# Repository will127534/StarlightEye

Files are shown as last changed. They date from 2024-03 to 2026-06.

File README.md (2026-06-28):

# StarlightEye: OpenSource IMX585 Camera Board for Raspberry Pi
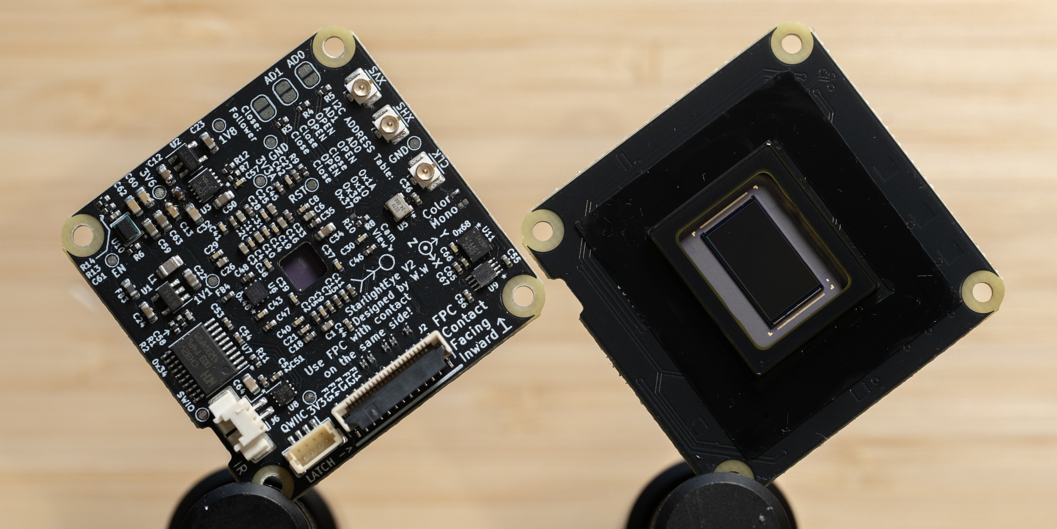
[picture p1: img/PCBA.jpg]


## Version 2.0 Changes
Mainly changed the power tree so now it does not require an external 5V input but the board can take all the power from FPC directly, there is a step-up converter that will step it up to 3.6V which is powering both IR filter switch (When used) and 3.3V analog LDO/1.8V Digital LDO input. By doing so the board size can finally shrink down to a perfect 39mm square which also matches the latest OneInchEye.  

The only down side is that the Step-Up convter I'm using here (TPSM83100) is expensive AF, I was going to pick TPSM81033 that is both cheaper and better but I have been waiting it to go on the market for four month now, I don't know when TI will actually get them ship to Mouser so for now I'm stuck with TPSM83100.  

_DSC9428

## Introduction
Welcome to the **StarlightEye** project, an open-source camera board designed for Raspberry Pi Compute Module 4 boards using the IMX585. This project aims to provide a high-quality, affordable, and accessible camera module for advanced Raspberry Pi projects. The board is designed using KiCad v6, a popular open-source electronics design automation (EDA) software.

StarlightEye captures stunning high-resolution images and videos with improved low-light performance and dynamic range. It's perfect for photography enthusiasts, developers, and makers who want to level up their Raspberry Pi projects with a powerful camera.  
  
Also see [Quick Start Guide](https://github.com/will127534/StarlightEye/wiki/StarlightEye-Quick-Start-Guide)

## Features
* IMX585 sensor
* **Open-source hardware and software**
* Integrated IR filter switch control via I2C based on CH32V003
* Integrated TMP117 temperature sensor
* Compatible with Raspberry Pi5 and Raspberry Pi Compute Module 4 boards with a 22-pin FPC connector and 4-lane MIPI-CSI (same pinout as Raspberry Pi Compute Module 4 IO Board)
* Limited amount on [https://shop.willwhang.dev/](https://shop.willwhang.dev/) for sell

## Notes
* Gerber and CPL file for JLCPCB is under /Gerber
* [Interactive BOM](https://htmlpreview.github.io/?https://github.com/will127534/StarlightEye/blob/main/bom/ibom.html) [(provided by InteractiveHtmlBom)
](https://github.com/openscopeproject/InteractiveHtmlBom) and JLCPCB BOM under /bom
* Source Code for CH32V003 based I2C controlled IR Filter Switch and Python code on RPI under /software

## Support
For questions, issues, or suggestions, please open an issue in the [GitHub repository](https://github.com/will127534/StarlightEye/issues)

## Schematic
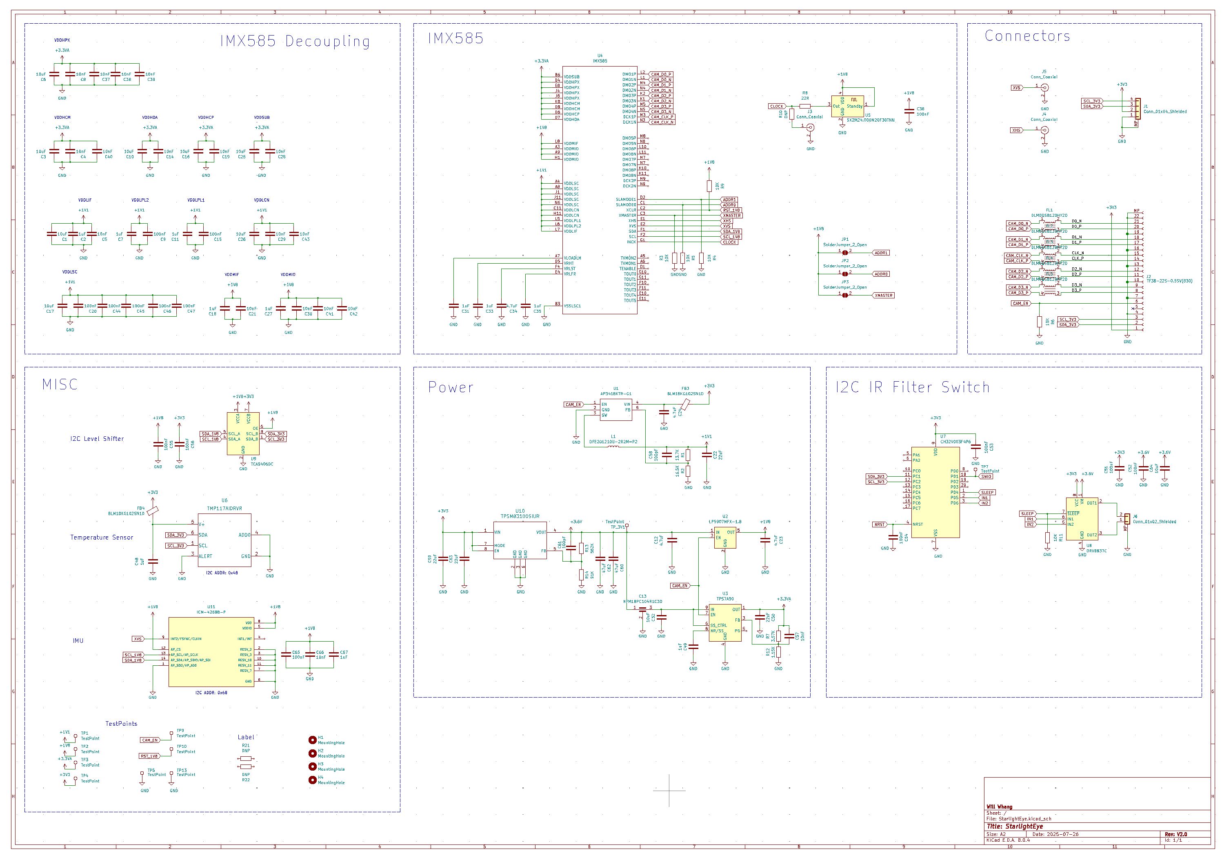
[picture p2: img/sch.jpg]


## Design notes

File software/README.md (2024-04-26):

# I2C IR Filter Switch

## Introduction
The I2C IR filter switch is based on CH32V003 acted as a I2C device, by default the I2C address is 0x34 and by writing 0x01 to enable IR filter or writing 0x00 to disable IR filter. The I2C connection is shared with the CMOS sensor on the StarlightEye.

## Install Python script on RPI
To install the script to your RPI, run the following cmd  
```
sudo wget https://raw.githubusercontent.com/will127534/StarlightEye/master/software/IRFilter -O /usr/local/bin/IRFilter && sudo chmod +x /usr/local/bin/IRFilter
```

## Example
The I2C bus will depend on which port you connect the StarlightEye to RPI5, by default CAM1 maps to I2C port 4 and CAM1 to port 6.
The default of the script is on CAM1, but you can add '--i2c-bus' flag to change it to other ports.
To enable IR filter:
```
IRFilter --enable
```
To disable IR filter:
```
IRFilter --disable
```

## Support
For questions, issues, or suggestions, please open an issue in the [GitHub repository](https://github.com/will127534/StarlightEye/issues)

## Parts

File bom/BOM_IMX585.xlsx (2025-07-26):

Comment | Designator | Footprint | JLCPCB Part #（optional）
NFM18PC104R1C3D | C13 | NFM18CC101R1C3D | C111493
10uF | C25,C26,C6,C10,C1,C16,C17,C3 | C_0402_1005Metric | C15525
1uF | C33,C27,C31,C18,C7,C67,C48,C49,C35,C2,C11 | C_0402_1005Metric | C52923
4.7uF | C34,C24,C23,C12 | C_0603_1608Metric | C19666
10nF | C43,C4,C21,C29,C28,C5,C8,C37,C57,C41,C66,C39,C42,C14,C19,C40,C38,C30 | C_0402_1005Metric | C15195
100nF | C52,C36,C54,C47,C55,C9,C20,C56,C51,C15,C53,C46,C44,C45,C65 | C_0402_1005Metric | C1525
22uF | C59,C50,C22,C63 | C_0603_1608Metric | C59461
47uF | C60,C62 | C_0603_1608Metric | C140782
100pF | C61,C58 | C_0402_1005Metric | C1546
10uF | C64,C32 | C_0603_1608Metric | C96446
BLM18KG102SN1D | FB3 | L_0603_1608Metric | C160982
BLM15PX330SZ1D | FB4 | L_0402_1005Metric | C2661673
DLM0QSB120HY2D | FL4,FL3,FL5,FL1,FL2 | DLM0QSB120HY2D | C3211477
Conn_01x04_Shielded | J1 | JST_SH_BM04B-SRSS-TB_1x04-1MP_P1.00mm_Vertical | C160390
TF38-22S-0.5SV(830) | J2 | TF38-22S-0.5SV(830) | C6552695
Conn_Coaxial | J4,J5,J3 | U.FL_Hirose_U.FL-R-SMT-1_Vertical | C5137195
Conn_01x02_Shielded | J6 | Molex_PicoBlade_53261-0271_1x02-1MP_P1.25mm_Horizontal | C189700
DFE201210U-2R2M=P2 | L1 | L_0805_2012Metric | C2049745
13.7K | R1 | R_0402_1005Metric | C25854
1.15K | R12 | R_0402_1005Metric | C29401
562K | R13 | R_0402_1005Metric | C48838
91K | R14 | R_0402_1005Metric | C4147
16.5K | R2 | R_0402_1005Metric | C25857
10K | R3,R11,R6,R5,R9,R4 | R_0402_1005Metric | C25744
3.57K | R7 | R_0402_1005Metric | C137991
22R | R8 | R_0402_1005Metric | C25092
AP3418KTR-G1 | U1 | SOT-23-5 | C500769
TPSM83100SIUR | U10 | MICROSIP8_SIU_TEX-L | C20346010
ICM-42688-P | U11 | PQFN50P300X250X97-14N | C1850418
LP5907MFX-1.8 | U2 | SOT-23-5 | C92498
TPS7A90 | U3 | Texas_S-PDSO-N10_EP1.2x2mm | C840111
SX2M24.000M20F30TNN | U5 | Oscillator_SMD_Abracon_ASDMB-4Pin_2.5x2.0mm | C2901600
TMP117AIDRVR | U6 | TMP117AIDRVR | C699536
CH32V003F4P6 | U7 | TSSOP-20_4.4x6.5mm_P0.65mm | C5187096
DRV8837C | U8 | WSON-8-1EP_2x2mm_P0.5mm_EP0.9x1.6mm | C191000
TCA9406DC | U9 | TCA9406DCUR | C840107
IMX585 | U4 | IMX283

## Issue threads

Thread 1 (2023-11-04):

LCSC part numbers?

tlalexander, 2023-11-04:
Hello,
Do you by chance have LCSC part numbers for this board? Some of them are easy to figure out, but I started trying to find an equivalent part for the Hirose FFC connector and I realized I should just ask first.
Thanks!

will127534, 2023-11-04:
check https://github.com/will127534/OneInchEye/blob/main/bom/BOM_JLCSMT.csv#L11
They are mostly the same.

I haven't send it to JLCPCB yet so don't have any part numbers to share yet.

will127534, 2023-11-04:
Actually I probably want to open this until I have the design send to JLCPCB

tlalexander, 2023-11-04:
Okay thanks!

tlalexander, 2023-11-04:
Ah interesting that the Hirose connector is marked as discontinued on LCSC with no stock indicated.
https://www.lcsc.com/product-detail/FFC-FPC-Connectors_HRS-Hirose-FH12A-22S-0-5SH-55_C3168813.html
https://jlcpcb.com/partdetail/Hirose-FH12A_22S_0_5SH_55/C3168813

will127534, 2023-11-04:
I guess you can swap it to a bottom-contact type:
[https://www.lcsc.com/product-detail/FFC-FPC-Connectors_HRS-Hirose-FH12-22S-0-5SH-55_C597981.html](https://www.lcsc.com/product-detail/FFC-FPC-Connectors_HRS-Hirose-FH12-22S-0-5SH-55_C597981.html)

But then you will need a FPC cable with one contact on the top and the other on the bottom of the FPC

will127534, 2023-11-04:
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

Some thing like this

tlalexander, 2023-11-04:
Okay great, thank you for finding a suitable part! I have seen cables like that around, shouldn't be too much trouble thanks.

phodina, 2024-01-12:
Hi @will127534 ,
speaking of the BOM and the parts - how do you solder the image sensor?

Do you let PCBWAY, JLCPCB or other manufacturer take care of that or do you solder the IMX585 IC yourself?

will127534, 2024-01-18:
@phodina I use low temperature paste and heat the board from the bottom with either heatgun or IR PCB pre-heater.

will127534, 2024-03-24:
Closing the issue with the updated design files

Closed 2024-03-24.

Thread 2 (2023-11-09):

IMX585 driver

petergerten, 2023-11-09:
That's a very interesting project!
I can't find the IMX585 driver - any hints?

will127534, 2023-11-10:
I do have the driver but I'm in the progress of updating it for RPI5, here is the V4l2subdevice driver sketch:
[https://gist.github.com/will127534/f734a32b18b44d57448b4e46d07bb1c7](https://gist.github.com/will127534/f734a32b18b44d57448b4e46d07bb1c7)

Will release once I sort out the issue.

petergerten, 2023-11-13:
@will127534 thanks!

In general can you tell me how much board specific this driver is?
E.g. to port it to a non-pi board with MIPI/CSI interface

will127534, 2023-11-13:
This is very specific for RPI, which non-pi board are you looking into?
If you know how to write camera driver for other platform I think it is actually not that bad because the driver only implements one mode and it is setup with the init-register array, so you just need to send those and setup the CSI receiver accordingly.

petergerten, 2023-11-20:
sorry for the late reply, I missed this message.

I am looking for integration with Qualcomm RB5 (https://www.qualcomm.com/developer/robotics-rb5-development-kit)

will127534, 2024-01-21:
[https://github.com/will127534/imx585-v4l2-driver/tree/main](https://github.com/will127534/imx585-v4l2-driver/tree/main)

Closed 2024-01-21.

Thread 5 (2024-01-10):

imx585 datasheet or description

deecct, 2024-01-10:
Hello! You made great work and it helps a lot for creating driver for image sensor.
I try to connect imx678 sensor to rockchip rv1126. I am starting to work on linux kernel driver for this images sensor. The imx678 sensor is very similar to imx585, at least the have identical resolution and both based on startvis2. Could you privately share the datasheet for imx585? Or may be sections that related with registers, functional and operation descriptions?

phodina, 2024-01-12:
@deecct This might help
 https://gitlab.com/kicad/libraries/kicad-symbols/-/merge_requests/4186#note_1723899202

node3112, 2024-01-18:
@deecct If you need the application notes and software reference manual, I am happy to share privately.

node3112, 2024-01-18:
Actually never mind, I'll just share here publicly.
[IMX585-AAQJ1.zip](https://github.com/will127534/StarlightEye/files/13975511/IMX585-AAQJ1.zip)

robertimorrison, 2024-02-21:
I have the full imx585 datasheet if you would like it.  Why sony tries to keep this stuff top secret is beyond me.

KharlamovVadim, 2024-02-27:
> I have the full imx585 datasheet if you would like it. Why sony tries to keep this stuff top secret is beyond me.

Hello!

Currently I am working on a project based on Novatek NT9856x EVB and IMX678. I have a datasheet from Sony, but it does not contain register addressing and contains a link to external application notes. Therefore, I am unable to adapt the IMX678 sensor to Novatek SDK based on Linux. I was able to find a mention of the sensor I was interested in only in this thread.

Could you please share the mentioned information about IMX678 (IMX585) in a private message? Perhaps there are also examples of driver implementations for this type of sensor?

If suddenly you have similar information on IMX471 and IMX363, then this is absolutely magic! These two types of sensors are next in line for driver development for this evaluation board.

If the other authors of the thread can also help, I would be very grateful!

KharlamovVadim, 2024-02-27:
> @deecct If you need the application notes and software reference manual, I am happy to share privately.

Hello!

Can you share privately to me please?

robertimorrison, 2024-02-27:
Vadim -- the datasheet I have is mostly about the hardware.  It describes how to write to chip registers, there is only a reference to an excel file (IMX585_Standard_Register_Setting) that probably gives better description of where they are and what they do.  I dont have the spreadsheet, likely essential for writing a driver.

I dont know how exactly to get private contact with you you can text me at 561-762-3314 (USA).

deecct, 2024-02-27:
@KharlamovVadim. I don't have full register map for imx678, but I have found purposes and values of several most important registers related with operation modes of this sensor. I can share it with you. The implementation of driver is similar to another sony's sensors if you use it as v4l2 subdevice.

P.S. I found an example of implementation here in github with "imx678" keyword. Maybe this [imx678.c](https://github.com/hailo-ai/linux-yocto-hailo/blob/b72dd07c41f7d7c74d979eb4fd549a0794f6e4e5/drivers/media/i2c/imx678.c ) will help you.

KharlamovVadim, 2024-02-28:
> Vadim -- the datasheet I have is mostly about the hardware. It describes how to write to chip registers, there is only a reference to an excel file (IMX585_Standard_Register_Setting) that probably gives better description of where they are and what they do. I dont have the spreadsheet, likely essential for writing a driver.
>
> I dont know how exactly to get private contact with you you can text me at 561-762-3314 (USA).

Thank you very much for your response!
In my case, I also only see the links "Please refer to IMX678_Standard_Register_Setting excel file" and "This sensor has the function as below. About detail, refer to each application note" in IMX678-AAQR1-C_E_Datasheet_E, but I don't have these documents.
Could you please share the information to my email v.a.kharlamov@outlook.com?

KharlamovVadim, 2024-02-28:
> @KharlamovVadim. I don't have full register map for imx678, but I have found purposes and values of several most important registers related with operation modes of this sensor. I can share it with you. The implementation of driver is similar to another sony's sensors if you use it as v4l2 subdevice.
>
> P.S. I found an example of implementation here in github with "imx678" keyword. Maybe this [imx678.c](https://github.com/hailo-ai/linux-yocto-hailo/blob/b72dd07c41f7d7c74d979eb4fd549a0794f6e4e5/drivers/media/i2c/imx678.c) will help you.

Thank you very much for your response!
Of course, imx678.c will help a lot.
Perhaps you can tell me where I can find similar drivers for IMX471 and IMX363, I managed to find something by searching on GitHub, but not everything suits me there.

Yes, I use v4l2, all drivers are designed approximately the same, but the difference is in working with various Sony sensors, including in the register map.

Could you please share the information you mentioned to my email v.a.kharlamov@outlook.com?

yhsyn0, 2024-03-04:
Hello everyone,
Also I need IMX678-AAQR1-C datasheet. I found the IMX585, but it is difficult to find a lens because its diagonal is 1/1.2. Could anyone please share the IMX678 datasheet with me ?
E-Mail: ejder391@gmail.com

robertimorrison, 2025-01-14:
Sam – I nearly as I can tell there are three levels of sony documentation for their image sensors:

1.	The marketing wank that is widely available and says nothing particularly useful;
2.	Datasheets that do provide pinouts, voltages and communication timings for almost-purely-hardware connections.  These are available but slightly difficult to find;
3.	A super-secret excel spreadsheet that sets out the sensor registers and their expected values for the sony sensor line.  The spreadsheet is referenced in the hardware data sheet in (2) above, but I’ve never seen it and don’t know anyone who has a copy.  (Will?)

Why sony regards the register spreadsheet as top secret-ultra-eyes-only for a product they presumably want to sell more of is beyond me.  Its all very Japanese and very strange.  Sony is not going to talk to you unless you are plausibly handing an order for 5-10k pieces and I wouldn’t even bother with Framos who are probably even less responsive than sony.

The sony sensor hardware is great; their business practices, not so much.

R. Morrison

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

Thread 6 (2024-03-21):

Where is the source code / driver

watchever, 2024-03-21:
Thanks a lot for this great project. This could be really interesting for a small project I am working on for astrophotography.
I am already working with an Arducam IMX462 sensor, but wondering where is the source code for the drivers on anything else for your sensor to be detected by Raspberry ? How do you communicate with the sensor ? Is it compatible with libcamera ?
Thanks

watchever, 2024-03-22:
Hi Will, I have found the IMX585 driver on your repository, sorry for the lazy request.
https://github.com/will127534/imx585-v4l2-driver

However I still have some questions.
What is max exposure for the sensor ? I have tried to reverse engineer the calculation in the IMX585 driver code source and found 8.4 sec, which sounds to be low for such a  light sensitive sensor, but my calculation is probably wrong. Can you tell me if I am wrong and if so what is max exposure ?

One more question, I guess that your dirver is libcamera compliant, but not so sure. Can you confirm ?

Thanks a lot for your help and great project. Really excited to try to build one of this and install it on raspberry.

I am working on a portable EEA system for astronomy, and if you are interested to cooperate, I will be more than happy to show you this project. Let me know.

Best

will127534, 2024-03-23:
Hi @watchever No worries, sorry for the delayed response.

The exposure calculation is:
Integration Time [s] = [{VMAX × (SVR + 1) – (SHR)} × HMAX + offset] / (72 × 10^6)

In the driver I did not use SVR,  so the max exposure time is  VMAX_max (20bit) x HMAX_max(16bit) / 72Mhz (let's ignore all the offsets). Which is 954.4 seconds.

The driver is indeed libcamera compliant, you can actually follow my IMX283 quick start guide, just replace the imx283 driver link to imx585.

I have more updates to share in the next few days (new HW design/setup guide), please do check-in on this project later!

will127534, 2024-03-23:
Quick question, what does EAA stands for?
I do see your(?) post here https://stargazerslounge.com/topic/401112-highly-portable-eea-device/

watchever, 2024-03-23:
Hi Will, thanks a lot for your reply, EAA stands for Electronic Assisted Astronomy. In short use sensitive sensor to see in realtime really faint objects like nebulae, galaxies which are nearly impossible to see with unaided eyes even with large telescope. And also apply some specific image post processing dedicated to astronomy to enhance details, reduce sensor noise,... That's what you see on the project you quote (yes that's my post). My purpose was to build a very portable EAA system which doesn't need a separate camera, computer, screen and lot of wires. You just insert this small box in the eyepiece holder of your scope, control it through a wifi connection with your smartphone, tablet or any other devices and see nebulae, galaxies with full details and color. That's why the IMX585 is just perfect for such a project. The present version is based on raspberry pi 4 and I am working to migrate on Rpi5 for performance reasons because realtime image processing really needs velocity.

will127534, 2024-03-24:
Just updated with the latest V1.6 design, tested with RPI5 along with a quick start guide.
We can move the discussion to [Discussions](https://github.com/will127534/StarlightEye/discussions).

Closed 2024-03-24.

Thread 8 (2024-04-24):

Where can you find the sensor ?

ecouter, 2024-04-24:
Hey ! As the title says i'm quite confused how you can get a imx585 sensor individually. Sony only sells to oems and I don't know any of them that would actually just sell the sensor instead of an integration in their product (beside frameos). Thanks for the help.

yassinebkr, 2024-04-27:
I think it is pretty impossible to find

hyperphonic0, 2024-04-29:
Have a look on AliExpress. Several vendors there have it.

yhsyn0, 2024-05-20:
Check Alibaba. I found the sensor for $69.5/pcs but it was not a detailed search. Maybe you can find better prices. Search for the full sensor name as IMX585-AAQJ1.

garlick, 2024-08-26:
As a data point: [Phase 1 Technology Corp](https://www.phase1vision.com/) is a US distributor of this sensor.  They have a minimum order of 10 parts and can provide data sheets and pricing on request.

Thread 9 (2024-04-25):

Missing R10 in bom

ZhouYixun, 2024-04-25:
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

Closed 2024-04-26.

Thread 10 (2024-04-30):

IMX585 Power – Horizontal banding and 3.3v power rail noise

robertimorrison, 2024-04-30:
IMX585 Power – Horizontal banding and 3.3v power rail noise
This is not an open issue post, rather a solved problem and note for other people who might encounter the same issue.  I built Will Whang’s excellent v1.0 IMX585 camera board using his driver and had severe problems with horizontal banding noise at higher analog gain values (>20 or so) in dark to darkish environments (late dusk to night).  Exactly the sorts of scenarios where the starvis 2 chips are supposed to excel.  At low gains and during the daytime, the sensor performed beautifully.

The IMX585 (and I would guess most/all of the sony starvis 2 sensors) are very sensitive to noise on the 3.3v supply rail and the pi5 3.3 volt supply (switchmode regulator?) is not up to the task.

Will’s original design powers the camera board off the pi’s MIPI 3.3v pin.  While exact details are hard to pin down from the intertubes, the rail appears to have enough overall current for the task (maybe 700mA available, vs total draw from the 585 of maybe 350mA), however the noise on the rail totally pollutes the image from the sensor at highish-to-high gain values.

I haven’t put an oscilloscope on the supply rail, but I think what is going on (just from watching the current output on my benchtop supply, now supplying the camera board) is at high gain the sensor photocell amplifiers demand a sudden big step up in current at the end of each exposure as the image data is read out, amplified, A/D converted and shoveled to the MIPI interface.   My guess is the Pi’s rail briefly rings in response, and the ring wrecks the performance of the on-sensor amps.  Dunno if some additional capacitance in the design would address the problem.  Roughly checking the camera board rails with a voltmeter didn’t reveal the problem, as it didn’t see the noise.

The solution was to isolate the camera board from the pi’s 3.3 volt source (I hacked through the trace on the camera board) and powered it from a linear 3.3 volt supply (presently a benchtop linear supply).

The two attached images illustrate the change, it should be obvious which is which.  The second line of the data displayed is the exposure in msec, the analog gain, the digital gain and the CPU temp.  The overall lighting of both scenes is dark.
A big thank you to Will and Tetsuya Nomura for their enormous hard work making these modern sensors function on the pi.
And since I’m under no NDA or any other obligations whatsoever to Sony, register 0x3030 (on the 585) is the analog gain multiplier that the starvis 2 chips have: a 0 in this register is the low-gain mode, 01, is high gain, but at the expense of higher noise.   Register 0x306C is the analog gain itself – I’ve run it up 250(dec) in high gain mode, and the noise is really quite acceptable.  Good job sony hardware engineers.

And finally a big hearty FU to sony for keeping all the register and basic datasheets so secret in the first place.  To the sony executives: what exactly is the point here in keeping technical information ultra-top secret for a single-sale product you are presumably interested in selling more of?  Lucky you guys have a talented engineering staff.   AFAIK, these sensors are not like john deere tractors where secret details allow you to charge usurious prices for follow-on field services.   If anything, the secrecy only encourages my (poor) hacking skills to reverse engineer and publicize the details.  If sony wants to sue me, see ya in court boys!

Cheers - Bob Morrison

robertimorrison, 2024-04-30:
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

robertimorrison, 2024-04-30:
I dont really know how to use guthub, but since this issue is resolved I'm going to try the "close with comment button"

will127534, 2024-05-03:
Bob,
Thank you so much on sharing the details and your work, I'm 100% with you and have the same issue with V1.0 on the RPI5. I did take a look at the oscilloscope and see quite some spikes on the 3.3V rail, so I went on designing the next version for RPI5 with that in mind but that is where the problem starts. RPI's FPC can only gives you 3.3V input, with the 3.3V analog rail my first attempt is to add a 3.3V to 5V step (For IR switch driver also), and a 3.3V LDO back to clean 3.3V analog. It turns out that the spikes when enabling the camera + FPC cable voltage drop causes the step-up converter to stop working. So in the end I roll it back to using a external 5V for the camera board power, and added step-down converter to 3.6V and then goes through 3.3V LDO for analog. This is also why the version jumps from v1.4 to v1.6.... I have a batch of failed v1.5.

I'm also with you on the datasheet, now it is even worse because you can find the leaked datasheets with some important registers, those misc register you need to set for different mode to function is now in a separate excel sheet (Facepalm). Like, imagine a world where you can just look up the datasheet online, purchase it from Mouser/Digikey...etc and just... make your own board. That will be really great for your goal of being more developer friendly, Sony.

will127534, 2024-05-03:
I tagged your issue in the v1.4 release, thank you so much sharing it!

Let me know how your project goes too!

Closed 2024-04-30.

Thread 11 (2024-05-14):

Simplifying Design

yhsyn0, 2024-05-14:
Hi, I want to customize and simplify the existing design with removing XVS, XHS, CLK_IN, XMASTER, ADDR0 and becuase I'm gonna use one sensor per device and thinking they are connected to each other but I'm not sure about sometings and have some questions. Also I don't want to use QWIIC. I'm asking questions assuming a few things, please correct me if I am wrong.

1- What XVS and XHS are doing ? If there aren't multiple sensor which need to be synchronized, are they necessary ? And what is the connection between XVS-XHS and Master-Slave ? I assume it will be used to synchronize the master with the slaves.
2- There is 24 MHz built-in oscillator.  When I look at the PCB picture in v1.4, I see that there is no external oscillator connected, so I assume that it can work without an extra clock source. How does it work if an external clock signal is given from the CLK_IN pin ?
3- According to the datasheet, multiple clock sources can be used, 24, 27, 37.125, 72 and 74.25 MHz. What are the advantages and disadvantages of higher clock speeds ? Can we count the FPS increase as one of them or does this only happen when using 8-lane instead of 4-lane ? Also, how many of these other clock speeds can the Raspberry Pi 5 handle ? lf I use a different clock source that the Raspberry Pi 5 can handle, all I need to do is change the part of the driver code related to the clock signal ?
4- What is the Master-Slave situation and what do XMASTER, ADDR0 and ADDR1 pins ?(Also I'm talking about i2c adress table on the board, what is default position, 0x1A) Again assuming that they are related to the use of multiple sensors, are they necessary if I'm gonna use one sensor and if there is no slave, am I the Master ?
5- If I don't use any of these pins I mentioned, will it work ?

I asked some things just to be sure. Thanks in advance for your answers.

will127534, 2024-05-17:
1.  XVS and XHS are output or input sync signals, you can remove that.
2. I'm not quite sure what is your question here, the sensor require clock signal to work, so there is a oscillator on v1.4 board providing 24Mhz signal, you can send external 1.8V clock signal to that pin if you want to remove it.
3. I don't know, this is more for supporting systems that are already using those crystal in the systems so you can save one oscillator on the board. It does not change the sensor readout speed, the only thing you need to do is adjust the driver code to initialize the sensor with correct PLL settings.
4. I'm not clear about what are you asking, but these are not necessary for single sensor usage. The master option is for XHS/XVS clock output/input selection, which if not use then you can ignore them.
5. You can leave XHS,XVS, Master Open and pull the AD0 and AD1 to GND to fix I2C address to 0x1A.

yhsyn0, 2024-05-17:
Thank you @will127534, you helped a lot. Maybe my questions were a bit confusing and not clear enough, but I got the answers I needed.
In the 2nd question, what I wanted to ask was what happens when an external oscillator is connected when there is already an internal oscillator. However, this question is just out of curiosity.
In the 4th question, I thought they had a relationship because the XMaster and ADD0-ADD1 pins were positioned close in the schematic, but now I realise that this is wrong.
Thank you again for your answers. I am currently working on a different sensor similar to the IMX585 based on your work.

will127534, 2024-05-19:
> In the 2nd question, what I wanted to ask was what happens when an external oscillator is connected when there is already an internal oscillator. However, this question is just out of curiosity.

There is a resistor on the board to switch between the two options, so you either do external or internal with the HW.

Closed 2024-05-19.

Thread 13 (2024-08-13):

STM8 or CH32

phodina, 2024-08-13:
Hi @will127534 ,
I checked the schematics and there's STM8 but all other READMEs and description mention the RISC-V processor.

What's the reason behind that inconsistency? Are these pin to pin compatible?
Also why not go for STM32? Is that due to price or chip sourcing?

Also how flash the processor? Does it have a bootloader over the I2C pins?

The reason why I ask is I'd like to build the project and I'm scratching my head over this :-)

will127534, 2024-09-03:
I just reused the STM8 footprints for CH32V003. There is no bootloader so you will have to flash it from the SWIO testpad on the board.

Closed 2024-09-03.

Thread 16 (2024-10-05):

Could a IMX585-AAMJ1 work ?

martin-zs, 2024-10-05:
The IMX585-AAMJ1 is a monochrome 3840 (H) × 2160 (V); approx. 8.29M pixel;  Maximum frame rate in All-pixel scan mode: 12 bit: 60 frame/s, 10 bit: 90 frame/s.

My thinking was that with a monochrome sensor, I would only need to remove the glass window over the sensor (which absorbs UV)  and replace with a window made out of UV fused silica or fused quartz. That way I would not have to deal with removing the Bayer filter. Basically to use the 4K sensor with raw data for spectroscopy from ~220 to ~ 1250 nm.

I'm was at the toying with the idea stage, when noticed your project and though that looks nearly perfect. Thanks in advance.

will127534, 2024-10-05:
Hell yeah.
I've been using monochrome IMX585 with this project for a while now, the driver also supports monochrome with the `dtoverlay=imx585,mono` flag.

Here is my experiment with UV photography - though I think the lens itself is absorbing UV.
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

will127534, 2024-10-05:
IMX585-AAMJ1= IMX585-AAQJ1 in terms of hardware (and actually software, just that you need to tell ISP that this is a monochrome sensor).

So if you can get the sensor then just drop it in.

will127534, 2024-10-05:
For me I'm mostly using it for H-alpha solar imaging
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

martin-zs, 2024-10-05:
Absolutely perfect, thank you. That is music to my ears. I am moving at the moment, but once moved I know what I'll be doing.

> So if you can get the sensor then just drop it in.
A quick search using "IMX585-AAMJ1 site:aliexpress.com", says that I probably can.

Closed 2024-10-06.

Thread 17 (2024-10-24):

Capabilities of this camera module in conjunction with RPI?

sammtan, 2024-10-24:
Hello. I would like to create the same design but to be used with another TDA4VM which have max video decode specs of 4K60FPS. What about Raspberry Pi for this camera module? Did it go with 4K90FPS as the image sensor specs?

I'm also considering another image sensor option that is closer to 60FPS, such as IMX678.

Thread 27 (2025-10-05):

What is the meaning of Master Clock Input (INCK) and what is the technical specs of Master/Slave mode of IMX585 ?

shahbazahmedshah, 2025-10-05:
Hi!

I am a newbie in imaging domain. Currently working for my application in which I am referencing this repo for hardware design of my own IMX585 custom sensor board.  I have the following questions:

1. Is INCK must be supplied by host processor (to which the cam is connected) or can it be generated on board via active oscillator?

2. What is the technical simplified meaning of the IMX585 to be in Master/ Slave mode as for my application I will only interface a single cam with my processor so do tell also how XVS/XHS are going to be used then along with I/O description?

3. Will I operate my sensor board in Master If my application required interfacing only this cam with processor. No multiple cam application.

4. What is the exact meaning and usage of SLAMODE0/1 as they are just open SMD jumpers in this board. How it will be used for my application.

5. My application processor datasheet mentions a signal titled "Master Clock Output" in MIPI CSI-2 description. Is it the signal to be connected as a clock to this IMX585?

Any help, related docs or anything useful is highly appreciated!

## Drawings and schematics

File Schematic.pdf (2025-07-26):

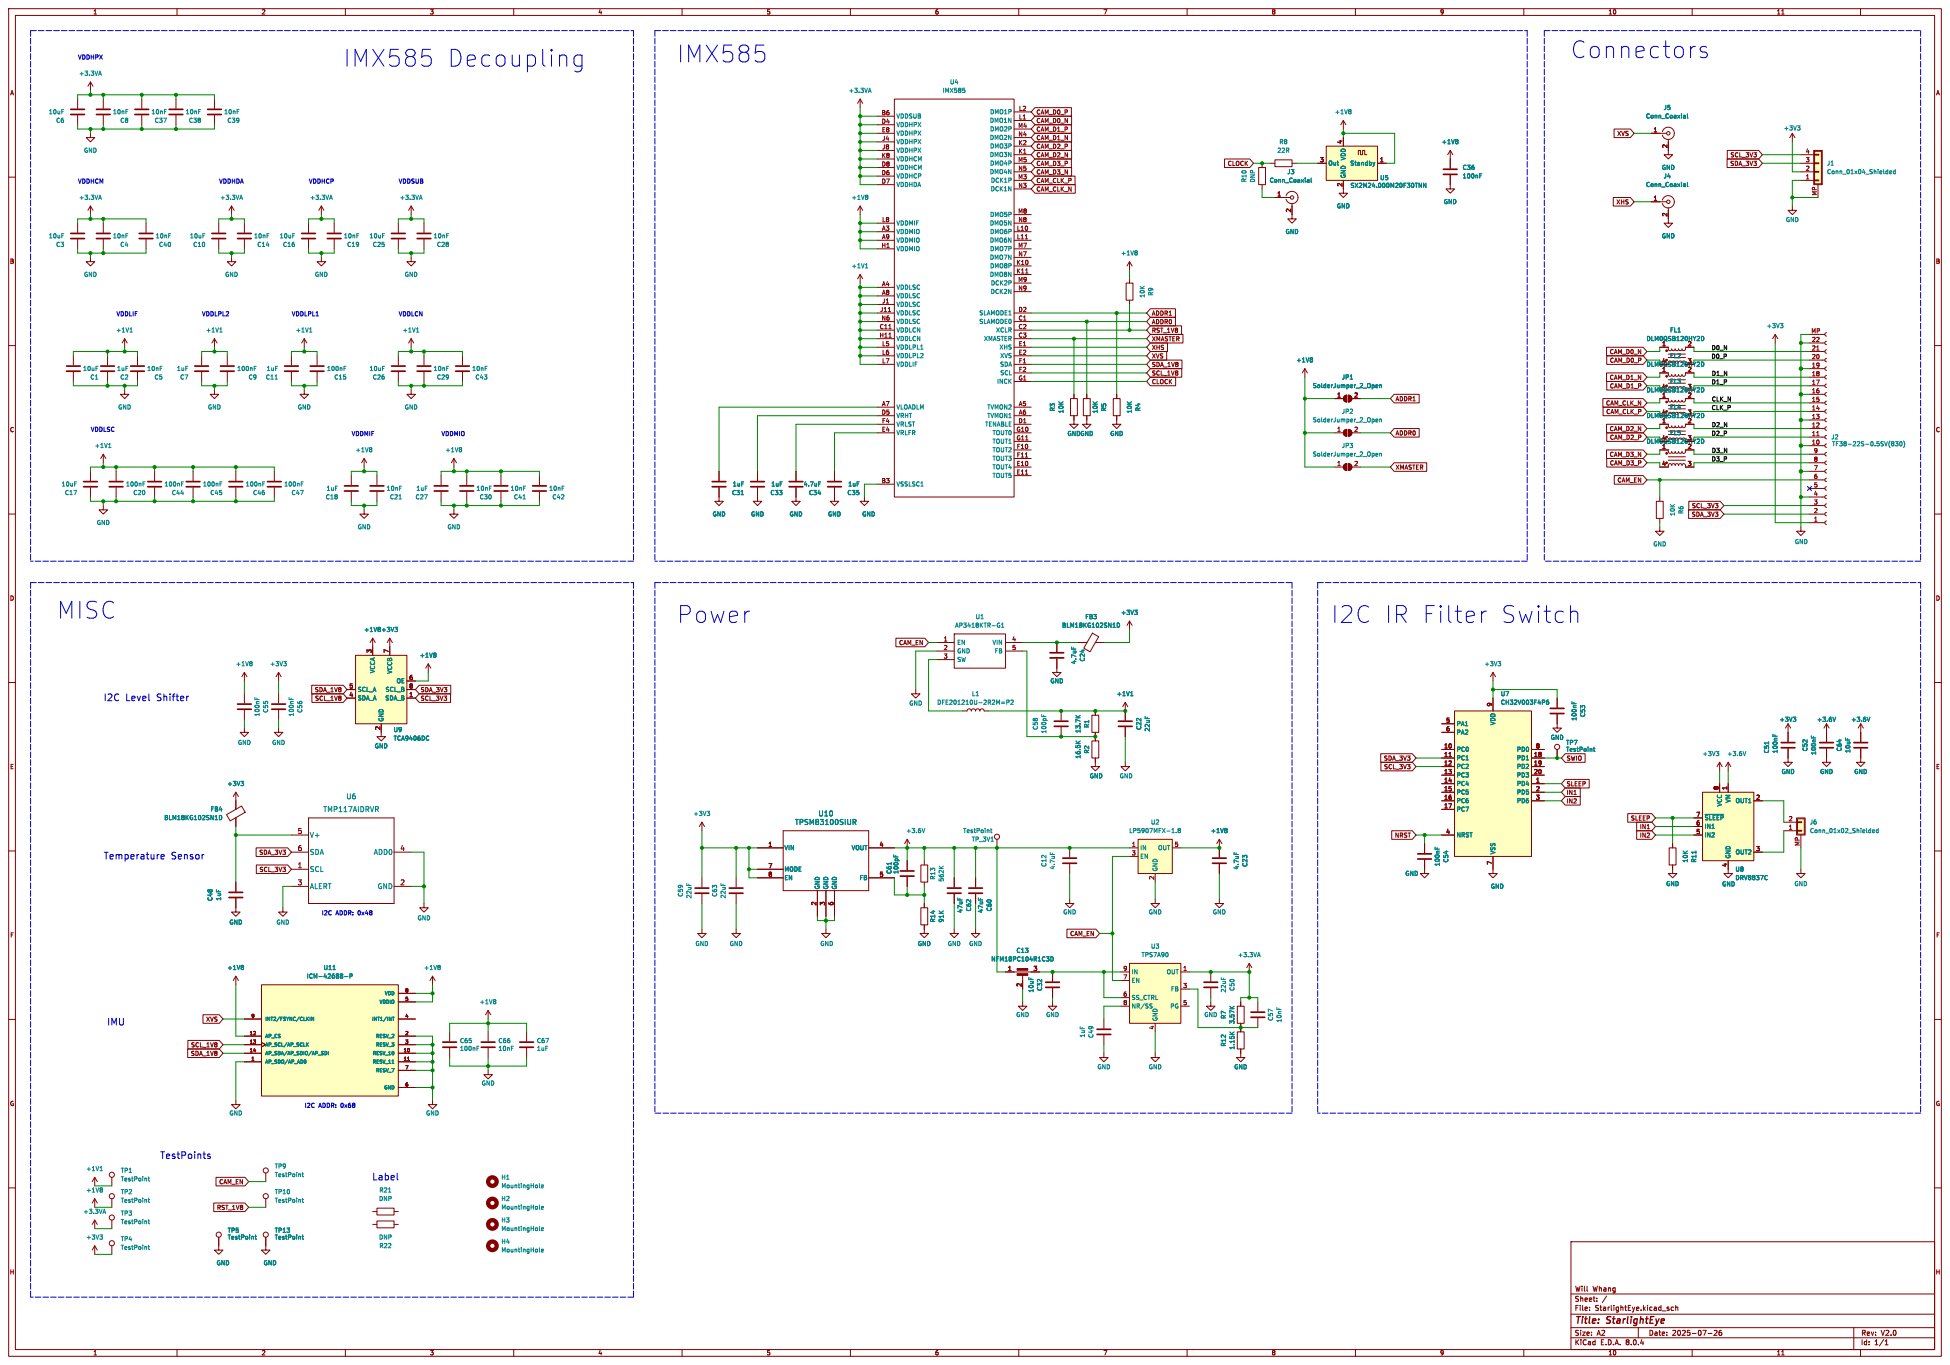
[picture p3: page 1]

File: StarlightEye.kicad_sch Sheet: / Will Whang

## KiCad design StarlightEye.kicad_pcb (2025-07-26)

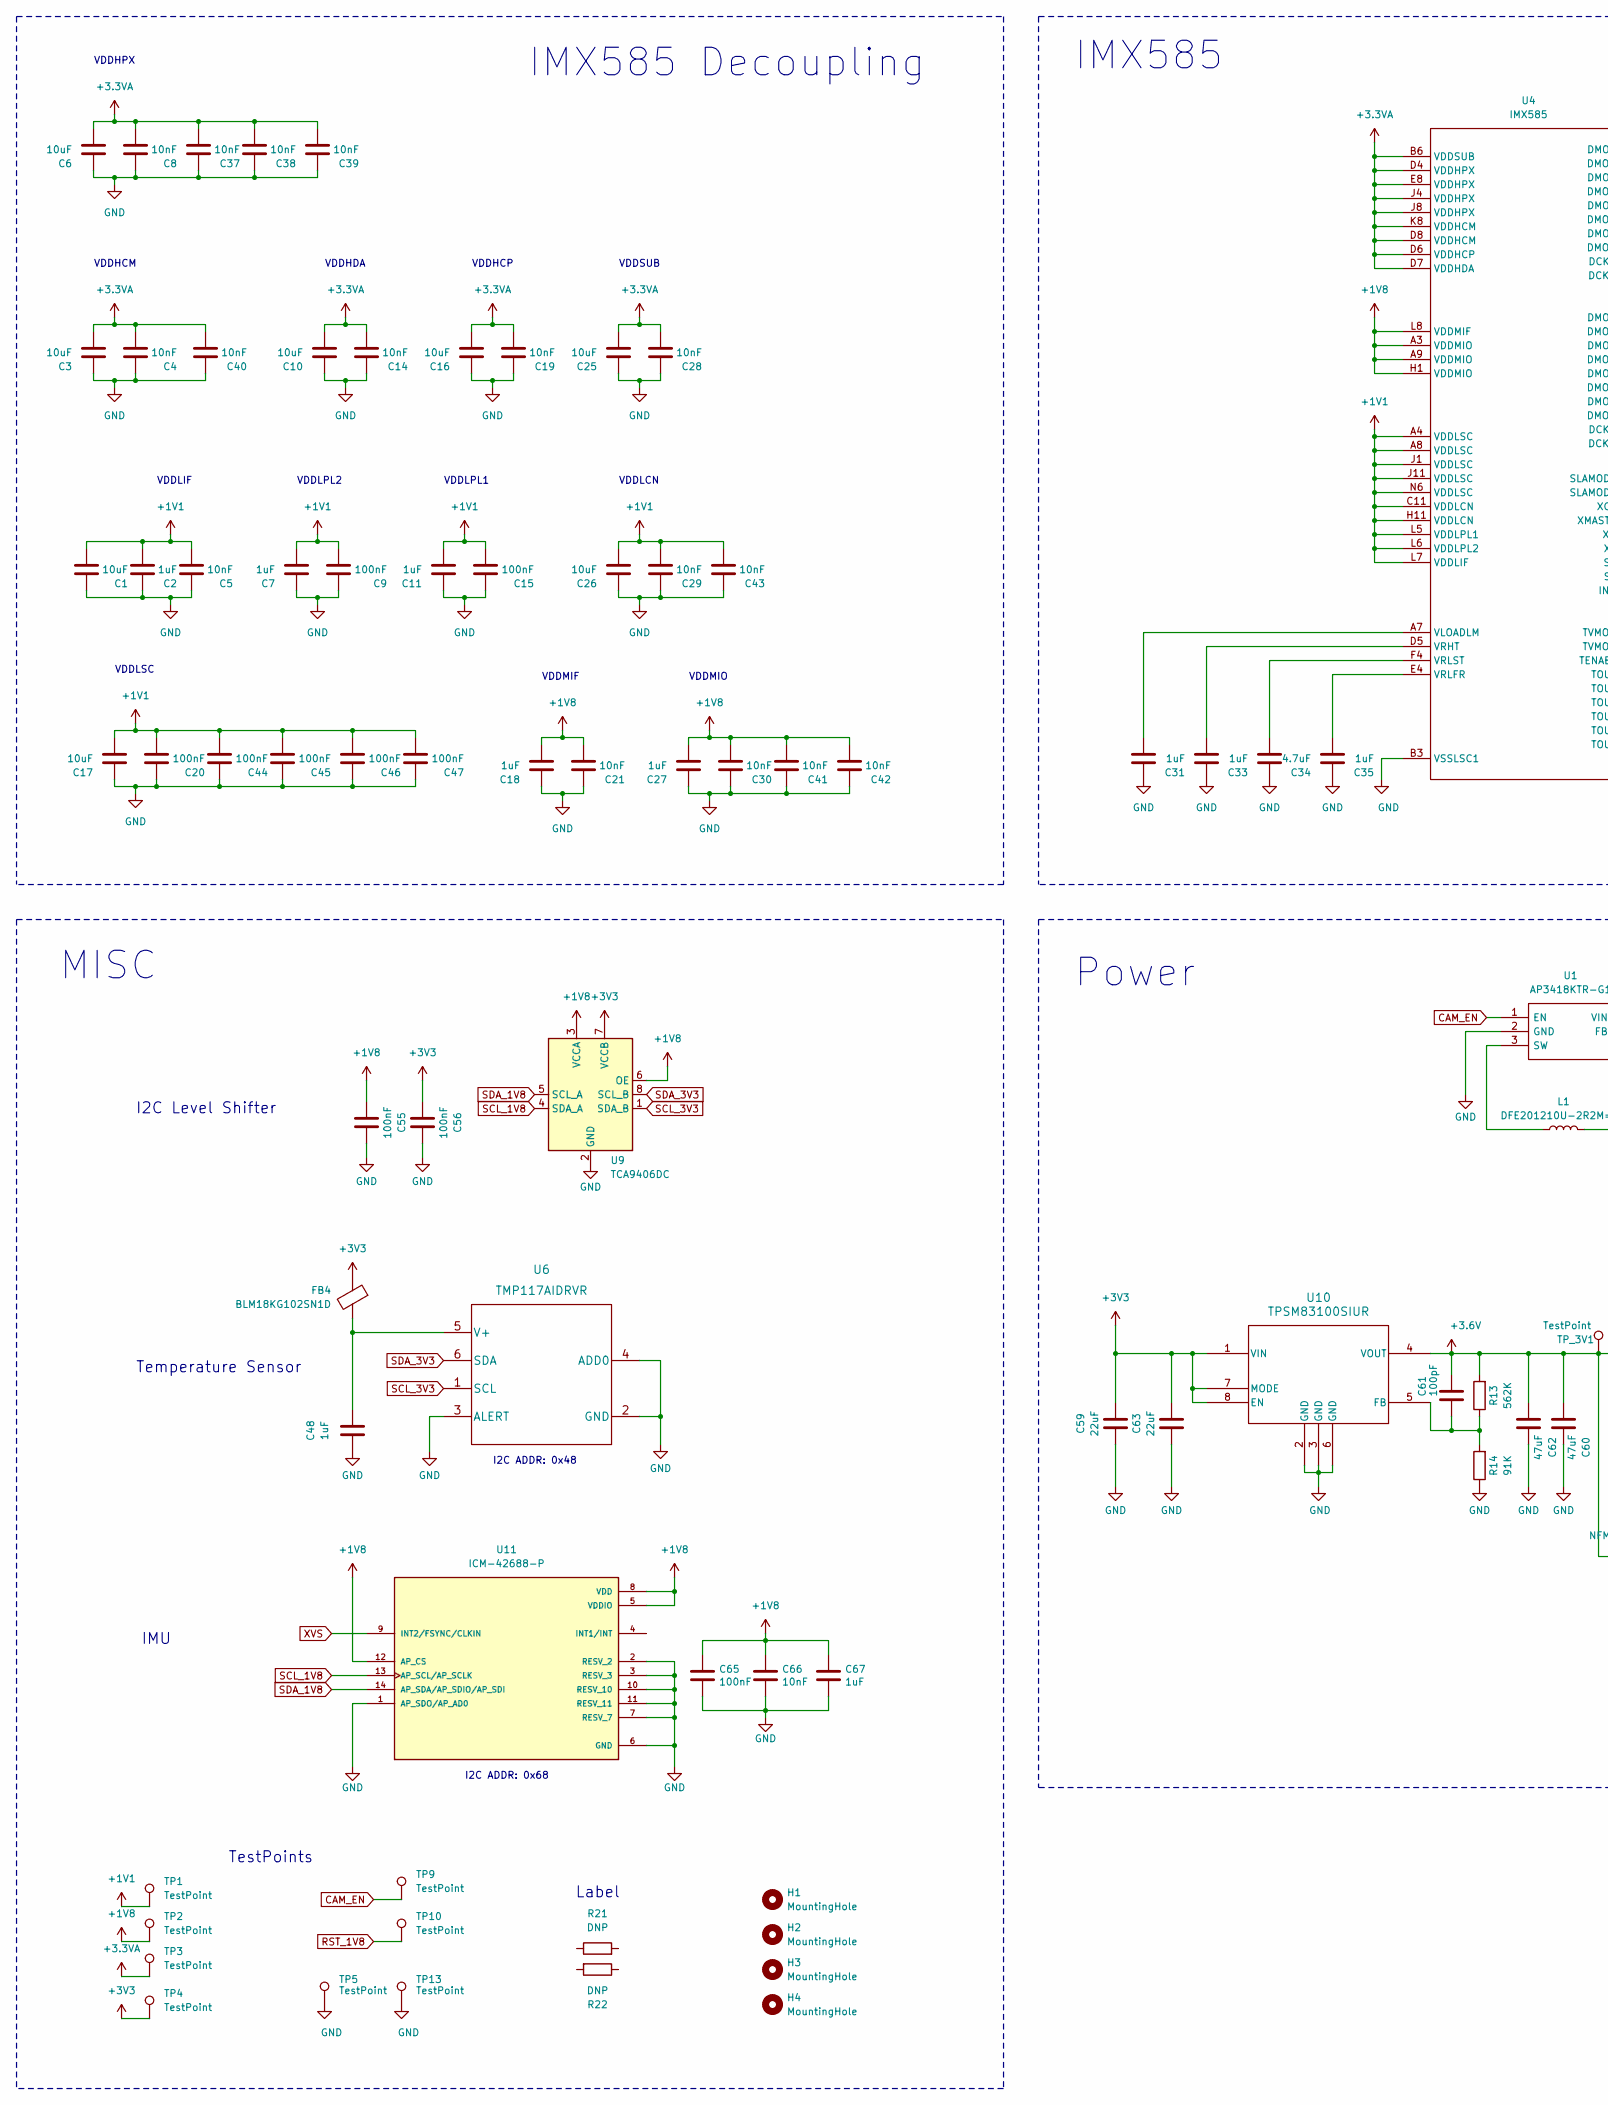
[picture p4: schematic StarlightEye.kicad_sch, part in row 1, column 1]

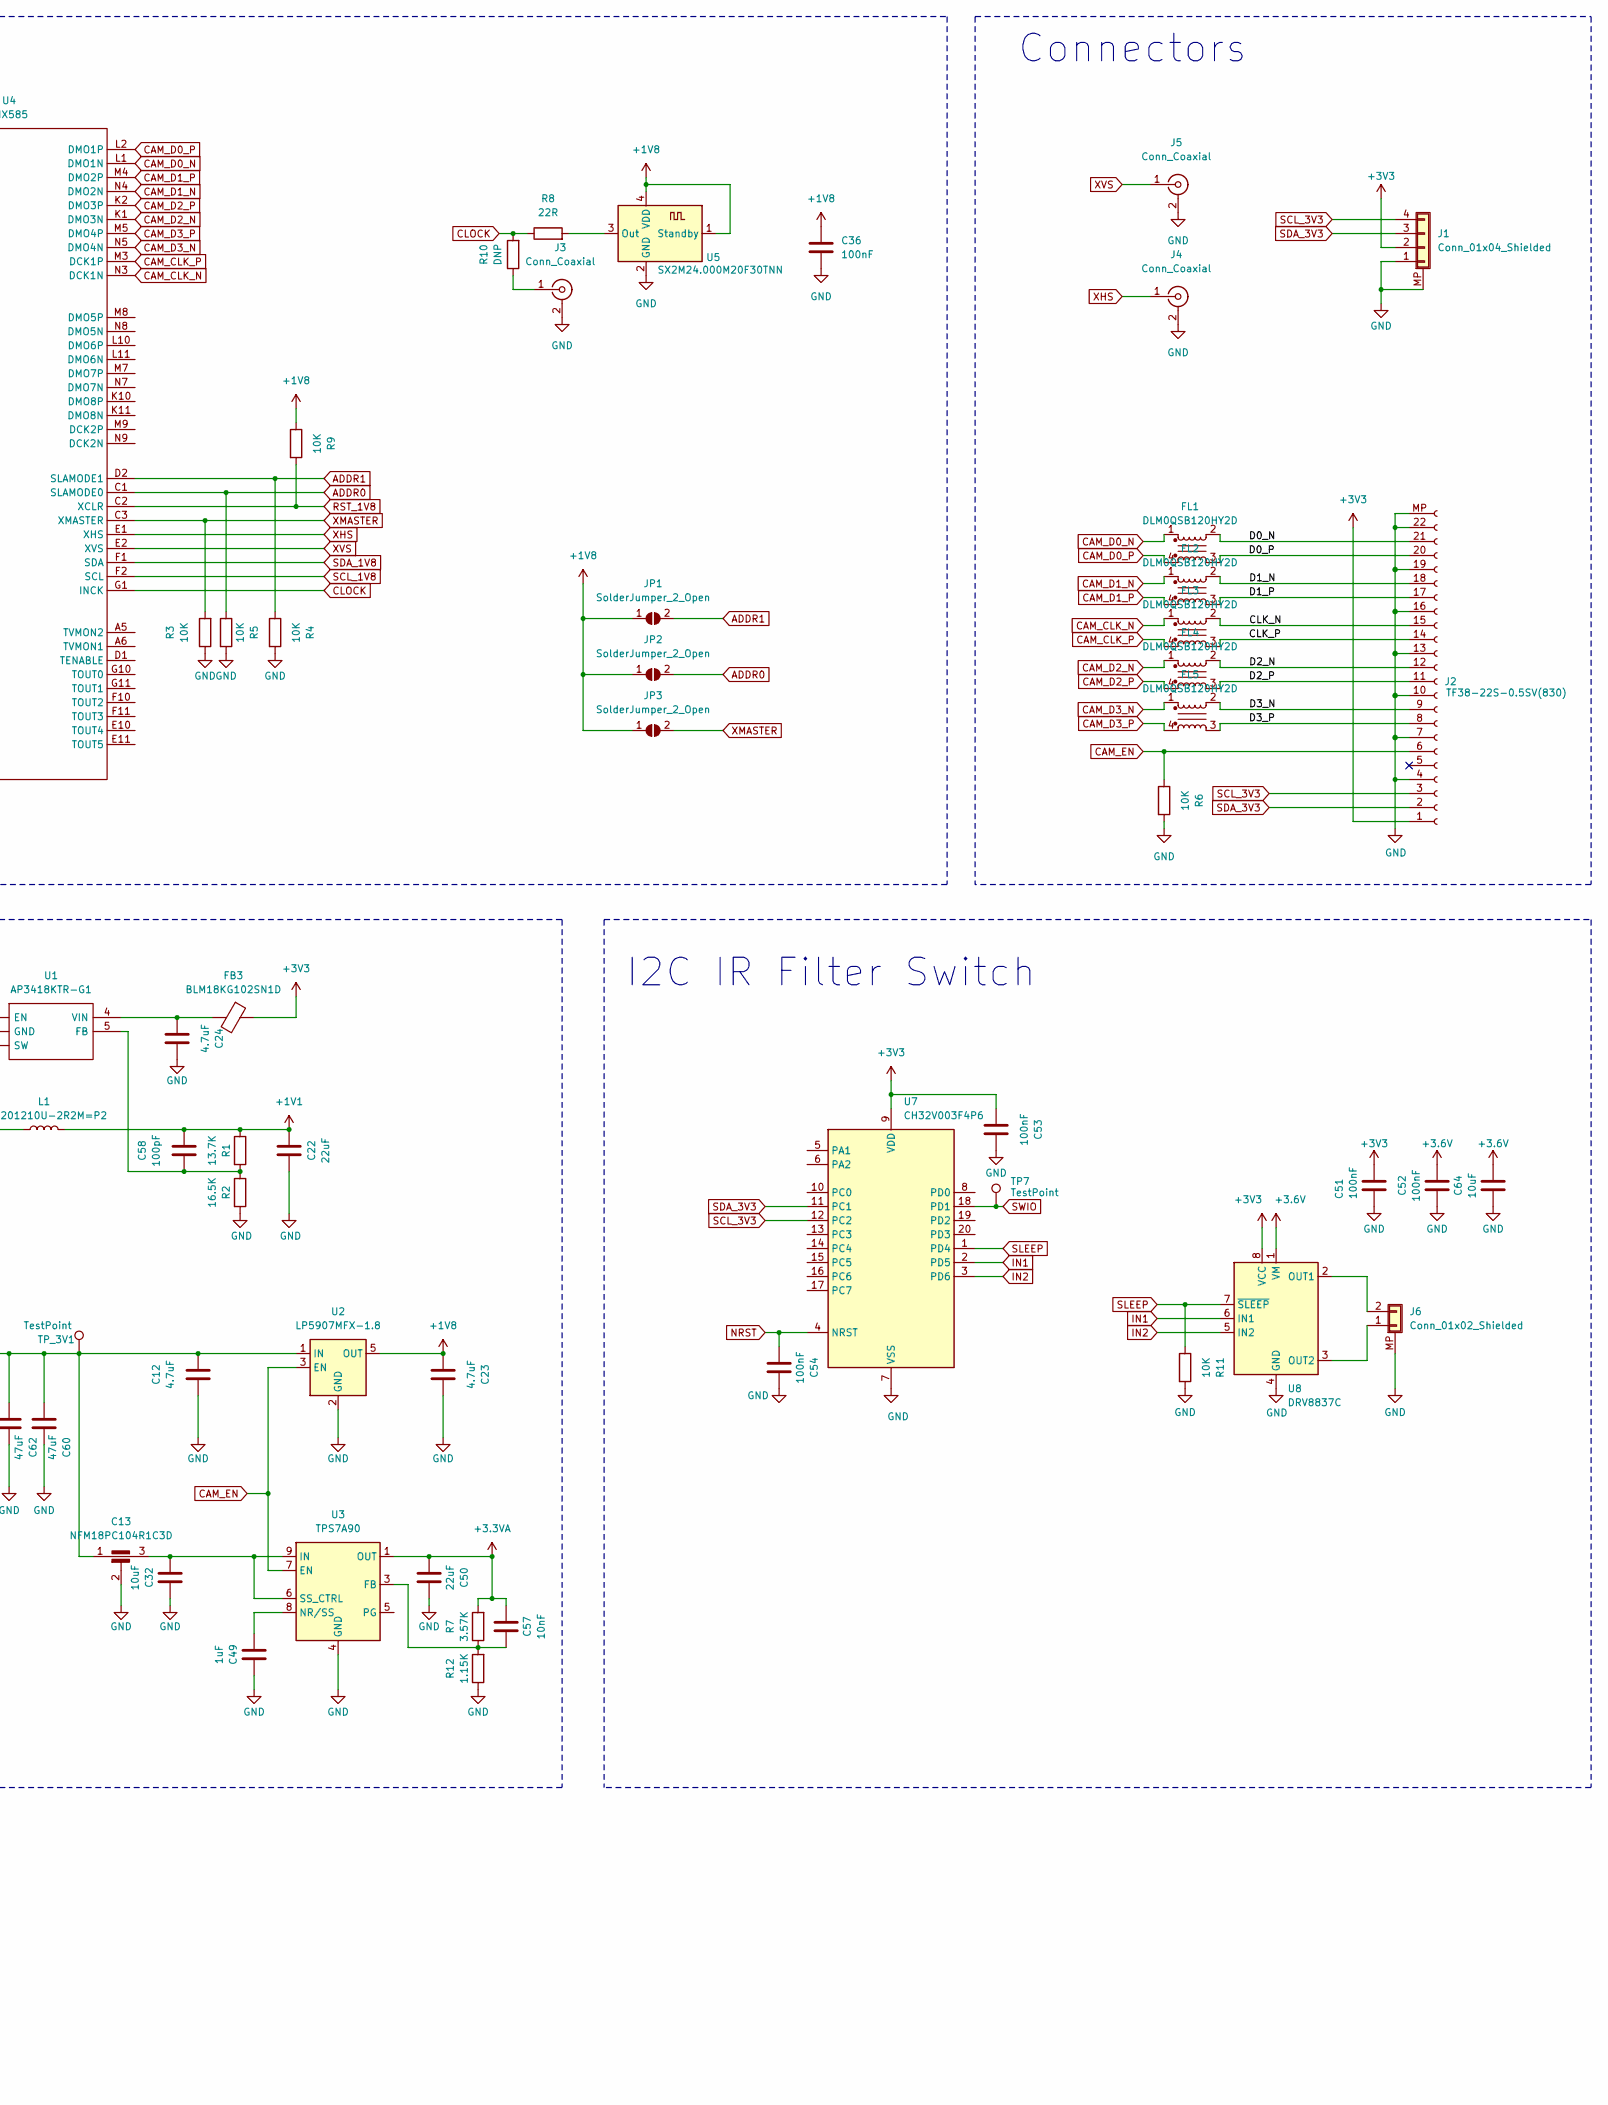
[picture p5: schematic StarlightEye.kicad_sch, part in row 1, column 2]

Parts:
C1, C3, C6, C10, C16, C17, C25, C26: 10uF; C_0402_1005Metric
C2, C7, C11, C18, C27, C31, C33, C35, C48, C49, C67: 1uF; C_0402_1005Metric
C4, C5, C8, C14, C19, C21, C28, C29, C30, C37, C38, C39, C40, C41, C42, C43, C57, C66: 10nF; C_0402_1005Metric
C9, C15, C20, C36, C44, C45, C46, C47, C51, C52, C53, C54, C55, C56, C65: 100nF; C_0402_1005Metric
C12, C23, C24, C34: 4.7uF; C_0603_1608Metric
C13: NFM18PC104R1C3D; NFM18CC101R1C3D
C22, C50, C59, C63: 22uF; C_0603_1608Metric
C32, C64: 10uF; C_0603_1608Metric
C58, C61: 100pF; C_0402_1005Metric
C60, C62: 47uF; C_0603_1608Metric
FB3: BLM18KG102SN1D; L_0603_1608Metric
FB4: BLM18KG102SN1D; L_0402_1005Metric
FL1, FL2, FL3, FL4, FL5: DLM0QSB120HY2D
H1, H2, H3, H4: MountingHole; MountingHole_2.2mm_M2
J1: Conn_01x04_Shielded; JST_SH_BM04B-SRSS-TB_1x04-1MP_P1.00mm_Vertical
J2: TF38-22S-0.5SV(830); TF3822S05SV830; Part Description 22 Position FFC, FPC Connector Contacts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
J3, J4, J5: Conn_Coaxial; U.FL_Hirose_U.FL-R-SMT-1_Vertical
J6: Conn_01x02_Shielded; Molex_PicoBlade_53261-0271_1x02-1MP_P1.25mm_Horizontal
JP1, JP2, JP3: SolderJumper_2_Open; SolderJumper-2_P1.3mm_Open_RoundedPad1.0x1.5mm
L1: DFE201210U-2R2M=P2; L_0805_2012Metric
R1: 13.7K; R_0402_1005Metric
R2: 16.5K; R_0402_1005Metric
R3, R4, R5, R6, R9, R11: 10K; R_0402_1005Metric
R7: 3.57K; R_0402_1005Metric
R8: 22R; R_0402_1005Metric
R10, R21, R22: DNP; R_0402_1005Metric
R12: 1.15K; R_0402_1005Metric
R13: 562K; R_0402_1005Metric
R14: 91K; R_0402_1005Metric
TP1, TP2, TP3, TP4, TP5, TP7, TP9, TP10, TP13: TestPoint; TestPoint_Pad_D1.0mm
TP_3V1: TestPoint; TestPoint_Pad_D1.0mm
U1: AP3418KTR-G1; SOT-23-5; Mouser Part Number 621-AP3418KTR-G1
U2: LP5907MFX-1.8; SOT-23-5
U3: TPS7A90; Texas_S-PDSO-N10_EP1.2x2mm
U4: IMX585; IMX283
U5: SX2M24.000M20F30TNN; Oscillator_SMD_Abracon_ASDMB-4Pin_2.5x2.0mm
U6: TMP117AIDRVR
U7: CH32V003F4P6; TSSOP-20_4.4x6.5mm_P0.65mm
U8: DRV8837C; WSON-8-1EP_2x2mm_P0.5mm_EP0.9x1.6mm
U9: TCA9406DC; TCA9406DCUR
U10: TPSM83100SIUR; MICROSIP8_SIU_TEX-L
U11: ICM-42688-P; PQFN50P300X250X97-14N; PARTREV 1.2

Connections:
+1V1: C1.2, C2.2, C5.2, C7.2, C9.2, C11.2, C15.2, C17.2, C20.2, C22.2, C26.2, C29.2, C43.2, C44.2, C45.2, C46.2, C47.2, C58.2, L1.2, R1.1, TP1.1, U4.A4 (VDDLSC), U4.A8 (VDDLSC), U4.C11 (VDDLCN), U4.H11 (VDDLCN), U4.J1 (VDDLSC), U4.J11 (VDDLSC), U4.L5 (VDDLPL1), U4.L6 (VDDLPL2), U4.L7 (VDDLIF), U4.N6 (VDDLSC)
+1V8: C18.2, C21.2, C23.1, C27.2, C30.2, C36.1, C41.2, C42.2, C55.1, C65.1, C66.1, C67.1, JP1.1 (A), JP2.1 (A), JP3.1 (A), R9.1, TP2.1, U2.5 (OUT), U4.A3 (VDDMIO), U4.A9 (VDDMIO), U4.H1 (VDDMIO), U4.L8 (VDDMIF), U5.1 (Standby), U5.4 (VDD), U9.3 (VCCA), U9.6 (OE), U11.5 (VDDIO), U11.8 (VDD), U11.12 (AP_CS)
+3.3VA: C3.2, C4.2, C6.2, C8.2, C10.2, C14.2, C16.2, C19.2, C25.2, C28.2, C37.2, C38.2, C39.2, C40.2, C50.1, C57.2, R7.2, TP3.1, U3.1 (OUT), U3.2 (OUT), U4.B6 (VDDSUB), U4.D4 (VDDHPX), U4.D6 (VDDHCP), U4.D7 (VDDHDA), U4.D8 (VDDHCM), U4.E8 (VDDHPX), U4.J4 (VDDHPX), U4.J8 (VDDHPX), U4.K8 (VDDHCM)
+3.6V: C12.2, C13.1, C52.2, C60.1, C61.1, C62.1, C64.2, R13.2, TP_3V1.1, U2.1 (IN), U8.1 (VM), U10.4 (VOUT)
+3V3: C51.1, C53.1, C56.1, C59.2, C63.2, FB3.1, FB4.1, J1.2, J2.1, TP4.1, U7.9 (VDD), U8.8 (VCC), U9.7 (VCCB), U10.1 (VIN), U10.7 (MODE), U10.8 (EN)
/CLK_N: FL3.2, J2.15
/CLK_P: FL3.3, J2.14
/D0_N: FL1.2, J2.21
/D0_P: FL1.3, J2.20
/D1_N: FL2.2, J2.18
/D1_P: FL2.3, J2.17
/D2_N: FL4.2, J2.12
/D2_P: FL4.3, J2.11
/D3_N: FL5.2, J2.9
/D3_P: FL5.3, J2.8
ADDR0: JP2.2 (B), R5.1, U4.C1 (SLAMODE0)
ADDR1: JP1.2 (B), R4.1, U4.D2 (SLAMODE1)
CAM_CLK_N: FL3.1, U4.N3 (DCK1N)
CAM_CLK_P: FL3.4, U4.M3 (DCK1P)
CAM_D0_N: FL1.1, U4.L1 (DMO1N)
CAM_D0_P: FL1.4, U4.L2 (DMO1P)
CAM_D1_N: FL2.1, U4.N4 (DMO2N)
CAM_D1_P: FL2.4, U4.M4 (DMO2P)
CAM_D2_N: FL4.1, U4.K1 (DMO3N)
CAM_D2_P: FL4.4, U4.K2 (DMO3P)
CAM_D3_N: FL5.1, U4.N5 (DMO4N)
CAM_D3_P: FL5.4, U4.M5 (DMO4P)
CAM_EN: J2.6, R6.1, TP9.1, U1.1 (EN), U2.3 (EN), U3.7 (EN)
CLOCK: R8.1, R10.2, U4.G1 (INCK)
GND: C1.1, C2.1, C3.1, C4.1, C5.1, C6.1, C7.1, C8.1, C9.1, C10.1, C11.1, C12.1, C13.2, C14.1, C15.1, C16.1, C17.1, C18.1, C19.1, C20.1, C21.1, C22.1, C23.2, C24.2, C25.1, C26.1, C27.1, C28.1, C29.1, C30.1, C31.1, C32.2, C33.1, C34.1, C35.1, C36.2, C37.1, C38.1, C39.1, C40.1, C41.1, C42.1, C43.1, C44.1, C45.1, C46.1, C47.1, C48.1, C49.2, C50.2, C51.2, C52.1, C53.2, C54.2, C55.2, C56.2, C59.1, C60.2, C62.2, C63.1, C64.1, C65.2, C66.2, C67.2, J1.1, J1.MP (Shield), J2.4, J2.7, J2.10, J2.13, J2.16, J2.19, J2.22, J2.MP, J3.2 (Ext), J4.2 (Ext), J5.2 (Ext), J6.MP (Shield), R2.2, R3.1, R4.2, R5.2, R6.2, R11.2, R12.1, R14.1, TP5.1, TP13.1, U1.2 (GND), U2.2 (GND), U3.4 (GND), U3.11 (GND), U4.B3 (VSSLSC1), U4.B4 (VSSLSC2), U4.B8 (VSSLSC3), U4.C5 (VSSHPX4), U4.C6 (VSSHCP5), U4.C7 (VSSHDA6), U4.C8 (VSSHPX7), U4.C10 (VSSLCN8), U4.D3 (VSSHPX9), U4.E3 (VSSHPX10), U4.F3 (VSSHPX11), U4.F8 (VSSHPX12), U4.G2 (VSSLPL213), U4.H2 (VSSLSC14), U4.H4 (VSSHPX15), U4.H8 (VSSHPX16), U4.H10 (VSSLCN17), U4.J2 (VSSLSC18), U4.J10 (VSSLSC19), U4.K3 (VSSLSC20), U4.K5 (VSSLPL121), U4.K6 (VSSLPL222), U4.K7 (VSSHPX23), U4.K9 (VSSLSC24), U4.L3 (VSSLSC25), U4.L9 (VSSLSC26), U4.M6 (VSSLSC27), U5.2 (GND), U6.2 (GND), U6.3 (ALERT), U6.4 (ADD0), U7.7 (VSS), U8.4 (GND), U8.9 (GND), U9.2 (GND), U10.2 (GND), U10.3 (GND), U10.6 (GND), U11.1 (AP_SDO/AP_AD0), U11.2 (RESV_2), U11.3 (RESV_3), U11.6 (GND), U11.7 (RESV_7), U11.10 (RESV_10), U11.11 (RESV_11)
IN1: U7.2 (PD5), U8.6 (IN1)
IN2: U7.3 (PD6), U8.5 (IN2)
NRST: C54.1, U7.4 (NRST)
unnamed: J3.1 (In), R10.1
unnamed: J6.1, U8.3 (OUT2)
unnamed: J6.2, U8.2 (OUT1)
unnamed: C58.1, R1.2, R2.1, U1.5 (FB)
unnamed: L1.1, U1.3 (SW)
unnamed: C24.1, FB3.2, U1.4 (VIN)
unnamed: C57.1, R7.1, R12.2, U3.3 (FB)
unnamed: C49.1, U3.8 (NR/SS)
unnamed: C13.3, C32.1, U3.6 (SS_CTRL), U3.9 (IN), U3.10 (IN)
unnamed: C31.2, U4.A7 (VLOADLM)
unnamed: C33.2, U4.D5 (VRHT)
unnamed: C35.2, U4.E4 (VRLFR)
unnamed: C34.2, U4.F4 (VRLST)
unnamed: R8.2, U5.3 (Out)
unnamed: C48.2, FB4.2, U6.5 (V+)
unnamed: C61.2, R13.1, R14.2, U10.5 (FB)
RST_1V8: R9.2, TP10.1, U4.C2 (XCLR)
SCL_1V8: U4.F2 (SCL), U9.4 (SDA_A), U11.13 (AP_SCL/AP_SCLK)
SCL_3V3: J1.4, J2.3, U6.1 (SCL), U7.12 (PC2), U9.1 (SDA_B)
SDA_1V8: U4.F1 (SDA), U9.5 (SCL_A), U11.14 (AP_SDA/AP_SDIO/AP_SDI)
SDA_3V3: J1.3, J2.2, U6.6 (SDA), U7.11 (PC1), U9.8 (SCL_B)
SLEEP: R11.1, U7.1 (PD4), U8.7 (~SLEEP)
SWIO: TP7.1, U7.18 (PD1)
XHS: J4.1 (In), U4.E1 (XHS)
XMASTER: JP3.2 (B), R3.2, U4.C3 (XMASTER)
XVS: J5.1 (In), U4.E2 (XVS), U11.9 (INT2/FSYNC/CLKIN)

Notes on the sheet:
VDDMIO
VDDLIF
TestPoints
VDDSUB
Connectors
IMU
VDDHPX
VDDLSC
VDDHCM
IMX585
VDDLCN
VDDLPL2
I2C ADDR: 0x48
VDDLPL1
Temperature Sensor
I2C Level Shifter
VDDHDA
IMX585 Decoupling
I2C IR Filter Switch
I2C ADDR: 0x68
VDDHCP
MISC
Power
Label
VDDMIF

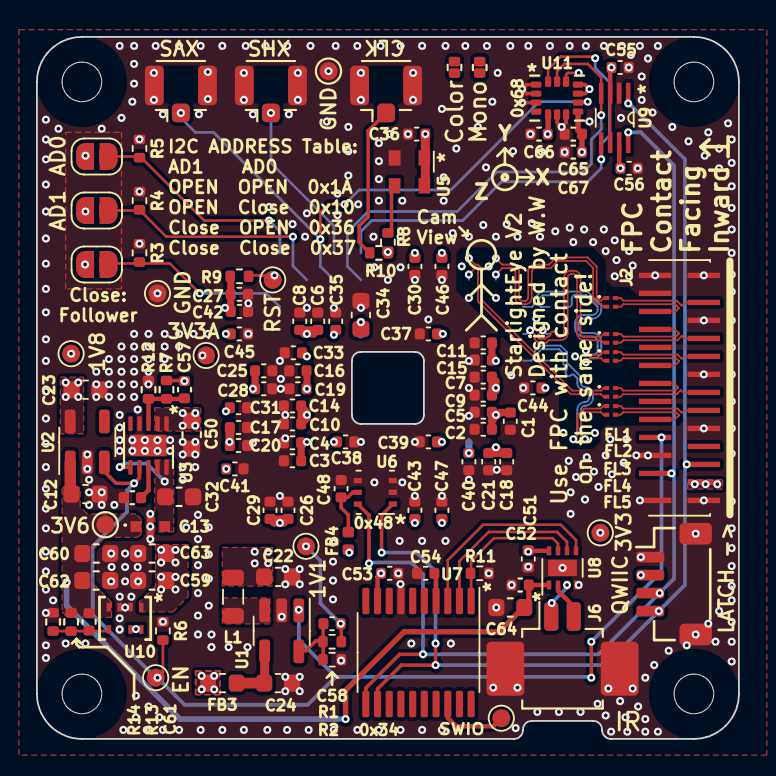
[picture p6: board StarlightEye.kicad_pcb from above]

Board: 4 copper layers, 39.0 x 39.0 mm, 125 parts (1 on the bottom side), 59 nets.

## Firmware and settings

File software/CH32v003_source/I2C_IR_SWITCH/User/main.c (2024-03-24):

#include "debug.h"

/* I2C Communication Mode Selection */
//#define I2C_MODE   HOST_MODE
#define I2C_MODE   SLAVE_MODE

/* Global define */
#define Size   6
#define RXAdderss   0x34 << 1

/* Global Variable */
u8 direction = 0;
u32 currentStep = 0;
volatile  u8 TxData = 0;



#define IR_CTRL_GPIO GPIOD
#define IR_SLEEP GPIO_Pin_4
#define IR_INA GPIO_Pin_5
#define IR_INB GPIO_Pin_6



/*********************************************************************
 * @fn      IIC_Init
 *
 * @brief   Initializes the IIC peripheral.
 *
 * @return  none
 */
void IIC_Init(u32 bound, u16 address)
{
    GPIO_InitTypeDef GPIO_InitStructure={0};
    I2C_InitTypeDef I2C_InitTSturcture={0};

    RCC_APB2PeriphClockCmd( RCC_APB2Periph_GPIOA | RCC_APB2Periph_GPIOD | RCC_APB2Periph_GPIOC | RCC_APB2Periph_AFIO, ENABLE );
    RCC_APB1PeriphClockCmd( RCC_APB1Periph_I2C1, ENABLE );

    //I2C
    GPIO_InitStructure.GPIO_Pin = GPIO_Pin_2;
    GPIO_InitStructure.GPIO_Mode = GPIO_Mode_AF_OD;
    GPIO_InitStructure.GPIO_Speed = GPIO_Speed_2MHz;
    GPIO_Init( GPIOC, &GPIO_InitStructure );

    GPIO_InitStructure.GPIO_Pin = GPIO_Pin_1;
    GPIO_InitStructure.GPIO_Mode = GPIO_Mode_AF_OD;
    GPIO_InitStructure.GPIO_Speed = GPIO_Speed_2MHz;
    GPIO_Init( GPIOC, &GPIO_InitStructure );

    GPIO_InitStructure.GPIO_Pin = GPIO_Pin_4;
    GPIO_InitStructure.GPIO_Mode = GPIO_Mode_Out_PP;
    GPIO_InitStructure.GPIO_Speed = GPIO_Speed_50MHz;
    GPIO_Init( GPIOD, &GPIO_InitStructure );

    GPIO_InitStructure.GPIO_Pin = GPIO_Pin_5;
    GPIO_InitStructure.GPIO_Mode = GPIO_Mode_Out_PP;
    GPIO_InitStructure.GPIO_Speed = GPIO_Speed_50MHz;
    GPIO_Init( GPIOD, &GPIO_InitStructure );

    GPIO_InitStructure.GPIO_Pin = GPIO_Pin_6;
    GPIO_InitStructure.GPIO_Mode = GPIO_Mode_Out_PP;
    GPIO_InitStructure.GPIO_Speed = GPIO_Speed_50MHz;
    GPIO_Init( GPIOD, &GPIO_InitStructure );


    I2C_InitTSturcture.I2C_ClockSpeed = bound;
    I2C_InitTSturcture.I2C_Mode = I2C_Mode_I2C;
    I2C_InitTSturcture.I2C_DutyCycle = I2C_DutyCycle_16_9;
    I2C_InitTSturcture.I2C_OwnAddress1 = address;
    I2C_InitTSturcture.I2C_Ack = I2C_Ack_Enable;
    I2C_InitTSturcture.I2C_AcknowledgedAddress = I2C_AcknowledgedAddress_7bit;
    I2C_Init( I2C1, &I2C_InitTSturcture );

    I2C_Cmd( I2C1, ENABLE );


    I2C_StretchClockCmd( I2C1, DISABLE );

    // Enable interrupts
    I2C1->CTLR2 |= I2C_CTLR2_ITBUFEN;
    I2C1->CTLR2 |= I2C_CTLR2_ITEVTEN; // Event interrupt
    I2C1->CTLR2 |= I2C_CTLR2_ITERREN; // Error interrupt

    NVIC_EnableIRQ(I2C1_EV_IRQn); // Event interrupt
    NVIC_SetPriority(I2C1_EV_IRQn, 2 << 4);
    NVIC_EnableIRQ(I2C1_ER_IRQn); // Error interrupt



}

/*********************************************************************
 * @fn      main
 *
 * @brief   Main program.
 *
 * @return  none
 */


u8 IR_DIR = 0;
u32 IR_timeout = 0;

int main(void)
{
    Delay_Init();

    IIC_Init( 400000, RXAdderss);

    GPIO_WriteBit(IR_CTRL_GPIO, IR_SLEEP, 0);
    GPIO_WriteBit(IR_CTRL_GPIO, IR_INA, 0);
    GPIO_WriteBit(IR_CTRL_GPIO, IR_INB, 0);

    while (1){
        if (IR_timeout > 0){
            IR_timeout --;
            if (IR_timeout == 0){
                GPIO_WriteBit(IR_CTRL_GPIO, IR_INA, 0);
                GPIO_WriteBit(IR_CTRL_GPIO, IR_INB, 0);
                GPIO_WriteBit(IR_CTRL_GPIO, IR_SLEEP, 0);
            }
        }
    }
}




void I2C1_EV_IRQHandler(void) __attribute__((interrupt));
void I2C1_EV_IRQHandler(void) {
    uint16_t STAR1, STAR2 __attribute__((unused));
    STAR1 = I2C1->STAR1;
    STAR2 = I2C1->STAR2;

    //GPIO_WriteBit(LED_GPIO, LEDB, 0);
    I2C1->CTLR1 |= I2C_CTLR1_ACK;

    if (STAR1 & I2C_STAR1_RXNE) { // Write event
        //GPIO_WriteBit(LED_GPIO, LEDB, !(I2C1->DATAR == 0x01));
        IR_DIR = (I2C1->DATAR == 0x01);
        if (IR_DIR>0) {
            GPIO_WriteBit(IR_CTRL_GPIO, IR_INA, 1);
            GPIO_WriteBit(IR_CTRL_GPIO, IR_INB, 0);
            GPIO_WriteBit(IR_CTRL_GPIO, IR_SLEEP, 1);
        }
        else{
            GPIO_WriteBit(IR_CTRL_GPIO, IR_INA, 0);
            GPIO_WriteBit(IR_CTRL_GPIO, IR_INB, 1);
            GPIO_WriteBit(IR_CTRL_GPIO, IR_SLEEP, 1);
        }
        IR_timeout = 64000;
    }
    if (STAR1 & I2C_STAR1_TXE) { // Read event
        //I2C1->DATAR = TxData;
    }
    //GPIO_WriteBit(LED_GPIO, LEDB, 1);
}

void I2C1_ER_IRQHandler(void) __attribute__((interrupt));
void I2C1_ER_IRQHandler(void) {
    uint16_t STAR1 = I2C1->STAR1;

    if (STAR1 & I2C_STAR1_BERR) { // Bus error
        I2C1->STAR1 &= ~(I2C_STAR1_BERR); // Clear error
    }

    if (STAR1 & I2C_STAR1_ARLO) { // Arbitration lost error
        I2C1->STAR1 &= ~(I2C_STAR1_ARLO); // Clear error
    }

    if (STAR1 & I2C_STAR1_AF) { // Acknowledge failure
        I2C1->STAR1 &= ~(I2C_STAR1_AF); // Clear error
    }
}

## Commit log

2023-07-06 Bug fix: swaping part no AP2161W with AP2171W to have the correct EN polarity
    [StarlightEye.kicad_pcb, StarlightEye.kicad_sch]
2024-03-24 V1.6 init
    [BOM_IMX585.xlsx, StarlightEye.kicad_pcb, StarlightEye.kicad_sch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]
2024-03-24 update readme to v1.6
    Adding I2C IR filter code
    Update PCBA images
    chmod +x on IRFilter
    Update images
    Update README.md
2024-04-26 Update to the correct v1.6 gerber
    [StarlightEye-B_Cu.gbr, StarlightEye-B_Mask.gbr, StarlightEye-B_Paste.gbr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]
2025-07-26 Ver 2.0 HW
    [BOM_IMX585.xlsx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]
